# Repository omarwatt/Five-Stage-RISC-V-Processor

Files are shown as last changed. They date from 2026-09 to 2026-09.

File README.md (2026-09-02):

# Five-Stage RISC-V Processor

## Project Overview

A VHDL processor project comparing single-cycle and five-stage pipelined implementations. The design explores instruction overlap, data forwarding, hazard handling, and the FPGA resource and clock-frequency cost of pipelining.

## Main Features

- IF, ID, EX, MEM, and WB stages with interstage registers.
- Forwarding from EX/MEM and MEM/WB, prioritizing the newer result and excluding register `x0`.
- Load-use stalling and control-flow flushing.
- Branch and jump resolution in the MEM stage.
- Separate 8 KiB instruction and 8 KiB data memories.
- Stage-level instruction/PC visibility and cycle, stall, and flush counters.

## Architecture

The pipelined variant distributes the datapath across five stages. A hazard unit controls stalls, forwarding supplies recent operands, and flushing discards instructions after a control-flow redirect. Multiplication is split across EX and MEM using partial products from the lower 16 operand bits.

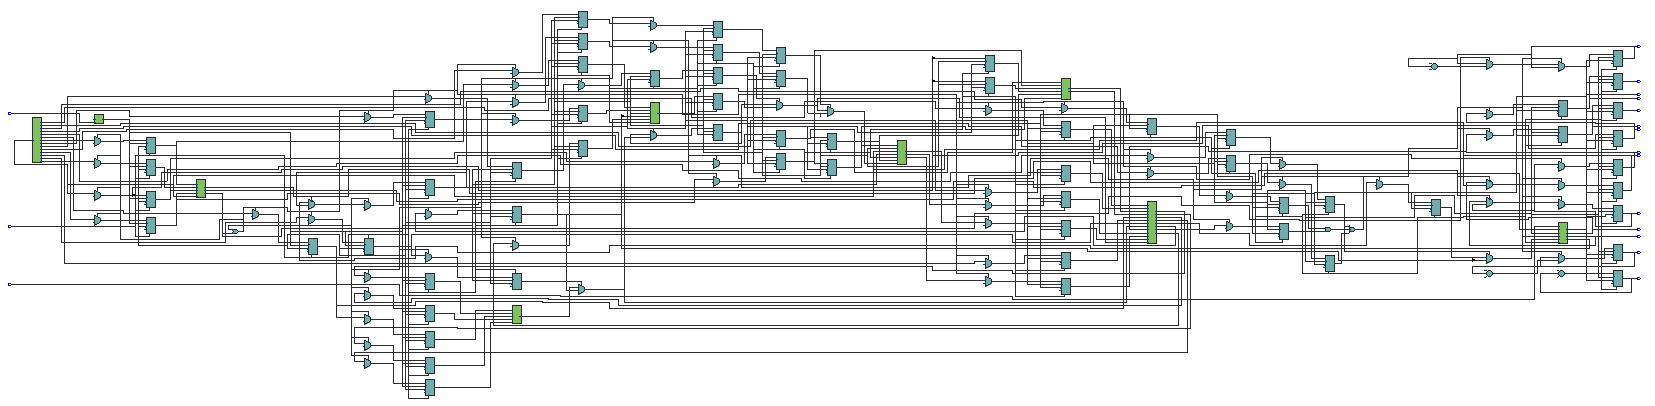
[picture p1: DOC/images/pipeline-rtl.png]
Pipelined processor RTL

*The report’s RTL view shows the processor blocks and interstage register banks.*

## Tools and Technologies

VHDL, Intel Quartus Prime 25.1, ModelSim/Questa, Intel FPGA memory primitives, and Cyclone V. The report also uses RARS as a software reference for program behavior.

## Simulation and Results

The report contains representative simulation and hardware-debug captures. The supplied testbenches provide directed stimulus rather than a complete automated ISA regression.

Archived results from `DOC/pre5.pdf`:

| Metric | Single-cycle | Pipelined |
| --- | ---: | ---: |
| Fitter ALMs | 1,448 | 1,705 |
| Fitter registers | 1,314 | 2,024 |
| MCLK Fmax | 34.99 MHz | 98.72 MHz |

The pipelined design raises reported maximum clock frequency while increasing resources. These figures do not establish application execution-time speedup.

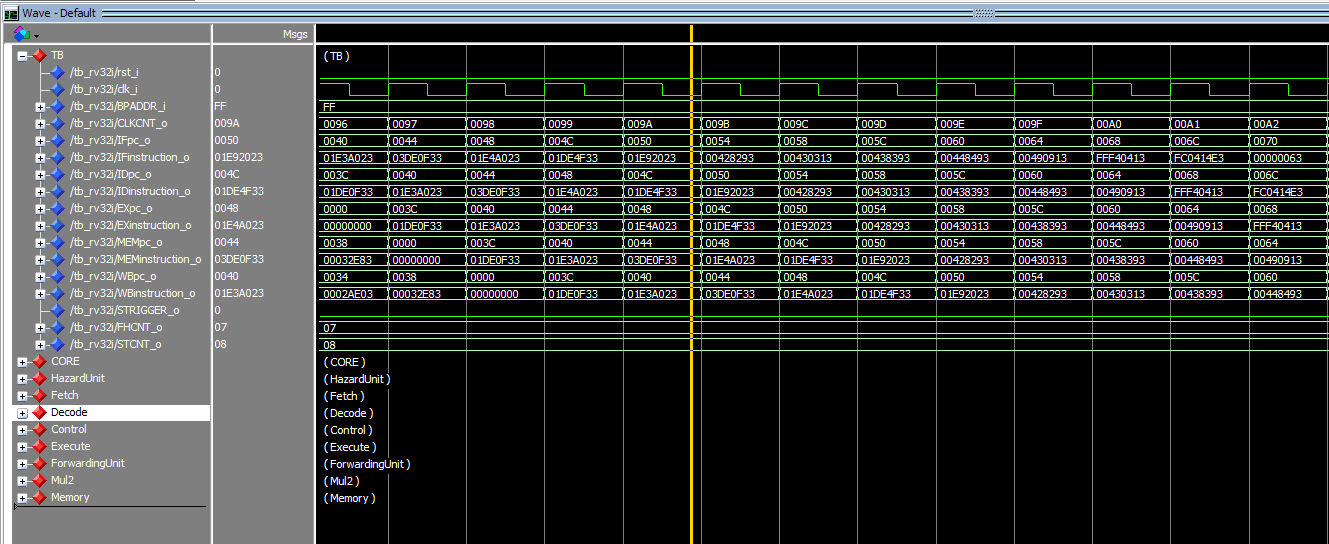
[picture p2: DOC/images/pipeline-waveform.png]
Pipeline simulation

*The IF, ID, EX, MEM, and WB program counters expose pipeline progression; STCNT and FHCNT show accumulated stalls and flushes.*

Pipeline timing result
*Quartus reports an MCLK Fmax of 98.72 MHz for the archived implementation.*

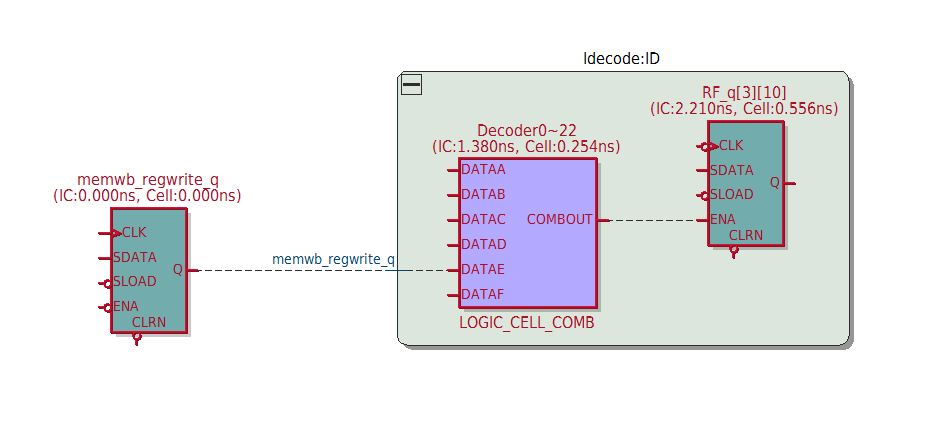
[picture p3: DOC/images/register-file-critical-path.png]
Register-file critical path

*The technology-map view traces memwb_regwrite_q through the IDECODE decoder to RF_q, locating the reported register-file write timing path.*

Pipelined data-memory readback
*The archived DTCM readback shows the benchmark’s stored result pattern. The report compares it with the single-cycle result and software reference.*

## Repository Structure

- `DUT/RV32IM_sc/`: single-cycle processor sources.
- `DUT/RV32IM_pipeline/`: pipelined processor sources.
- `TB/`: testbenches for the two variants.
- `DOC/`: project report.
- `docs/images/`: five selected design and results figures.
- `QUARTUS/`: archived implementation/debug artifacts.

## How to Run

1. Create a separate simulator project or work library for each variant: their entity and package names overlap.
2. Enable VHDL-2008 and configure Intel's `altera_mf` simulation library.
3. Set the selected variant's `G_MODELSIM` constant to `1`.
4. Supply matching instruction/data initialization images and replace the absolute paths in the memory sources.
5. Compile the selected variant's packages and DUT files in dependency order, then its testbench. Elaborate and inspect stage signals, register writes, and memory results.

## Attribution

Course project by **Omar Wattad**, based on the supplied course framework. Preserve the original source headers and course attribution.

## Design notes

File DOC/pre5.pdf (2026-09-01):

LAB5 — Single-Cycle & Pipelined RV32IM µArchitecture

Advanced CPU Architecture · Hanan Ribo · BGU Page 1 of 14

### Ben-Gurion University of the Negev

Electrical & Computer Engineering

Advanced CPU Architecture & Hardware Accelerators
Course 361-1-4693

# LAB 5 — Preparation Report

### Scalar Single-Cycle & 5-Stage Pipelined RV32IM CPU µArchitecture

Submitted by:
Omar Wattad — ID 207510819 Fidaa Abo Aissa — ID 324960996

Instructor: Hanan Ribo
June 2026

## Table of Contents

5. HDL Source File Descriptions | Error! Bookmark not defined.
7. FPGA Implementation | Error! Bookmark not defined.
8. Submission Structure | Error! Bookmark not defined.

## 1. Aim and Assignment Definition

This report documents the design, synthesis, implementation and validation of a RISC-V compatible CPU on an Intel FPGA, in two micro-architectural variants that share the same RV32IM (MULDIV-partial) instruction set:

- Part 1 — a scalar single-cycle RV32IM core, obtained by elevating the supplied single-cycle RV32I datapath with the M-extension mul instruction.
- Part 2 — a scalar 5-stage pipelined RV32IM core, obtained by slicing the single-cycle datapath into IF / ID / EX / MEM / WB stages with full data-forwarding, combinational hazard (interlock) detection, and branch/jump resolution in stage 4.
Both cores follow a Harvard organisation with separate ITCM (instruction) and DTCM (data) tightly-coupled memories of 8 kB each, a standard RISC-V register file, and a structural top level. A single PLL-derived clock (MCLK) drives the design; push-button KEY0 is the active core reset that brings the PC to the first program instruction.

### 1.1 The mul instruction and the 16-bit multiplier

From the M-extension only mul rd, rs1, rs2 is required. It multiplies the lower 16-bit half-words of rs1 and rs2 and writes the 32-bit product to rd. The 16×16 multiplication is built from the FPGA’s embedded 8-bit multipliers using four partial products:

- P0 = A_low × B_low, P1 = A_low × B_high, P2 = A_high × B_low, P3 = A_high × B_high
- M = P1 + P2, RESULT = P0 + (M << 8) + (P3 << 16)
In the single-cycle core the multiplier is purely combinational. In the pipeline it is split across two stages — the four partial products are formed in EX (Multiplier stage 1) and combined/shifted in MEM (Multiplier stage
2) — which keeps the multiplier off the critical path.

### 1.2 Signal-Tap instrumentation (IPC & breakpoint debug)

To support on-board IPC measurement and breakpoint debugging the top entity exposes the following registers, all cleared on reset:

- STCNT_o — 8-bit stall counter, increments on every clock in which a stall occurs.
- FHCNT_o — 8-bit flush counter, increments on every clock in which a flush occurs.
- BPADDR_i — 8-bit breakpoint address fed by SW7–SW0; the Signal-Tap trigger fires when IF_PC == BPADDR_i, letting us capture core signals from any PC until the buffer is full.
The instructions-per-cycle figure is verified against the relation

IPC = ( CLKCNT_o − (STCNT_o + 4 + depth · FHCNT_o) ) / CLKCNT_o = InstructionCounter / CLKCNT_o , IPC = 1/CPI

## 2. Top-Level Block Review

Both cores are structural top entities. The single-cycle top entity exposes the architectural state and datapath observation ports together with a free-running MCLK cycle counter; the pipelined top entity additionally exposes per-stage PC/instruction taps plus the stall, flush and trigger registers required for IPC and breakpoint debugging. Their I/O is summarised below.

Port | Single-cycle RV32IM_CORE | Pipelined RV32IM_CORE
Clock / reset | clk_i (50 MHz → PLL), rst_i (KEY0) | clk_i (50 MHz → PLL), rst_i (KEY0)
Debug input | — | BPADDR_i (SW7–SW0)
PC / instruction | pc_o, instruction_o | IF/ID/EX/MEM/WB pc_o & instruction_o
Control taps | RegWrite_ctrl_o, MemWrite_ctrl_o, Branch_ctrl_o, brTaken_o | (per-stage, internal)
Datapath taps | read_data1_o, read_data2_o,
write_data_o, alu_res_o | (per-stage, internal)
Memory taps | dtcm_addr_o, dtcm_data_wr_o, dtcm_data_rd_o | (internal)
Counters | mclk_cnt_o | CLKCNT_o, STCNT_o, FHCNT_o, STRIGGER_o

Table 1: Top-level port map of the single-cycle and pipelined RV32IM cores.

Each core instantiates five datapath sub-blocks — IFETCH, IDECODE, CONTROL, EXECUTE and DMEMORY — plus an altpll PLL that generates MCLK and an MCLK counter. The pipelined core adds four pipeline-register banks (IF/ID, ID/EX, EX/MEM, MEM/WB), a combinational Stall-Condition (hazard) unit and a Forwarding unit. The structural decomposition is visible in the RTL Viewer output of Section 3.

## 3. RTL Viewer Results

The Quartus RTL Viewer confirms the structural hierarchy of each core. In the single-cycle netlist the five submodules (control:CTL, Ifetch:IFE, Idecode:ID, Execute:EXE, dmemory:MEM), the PLL\G0:MCLK and the mclk_cnt register are clearly separated, with the combinational datapath flowing left-to-right in a single clock. The pipelined netlist shows the same datapath sliced by the four register banks, producing the characteristic columns of edge-triggered registers between stages.

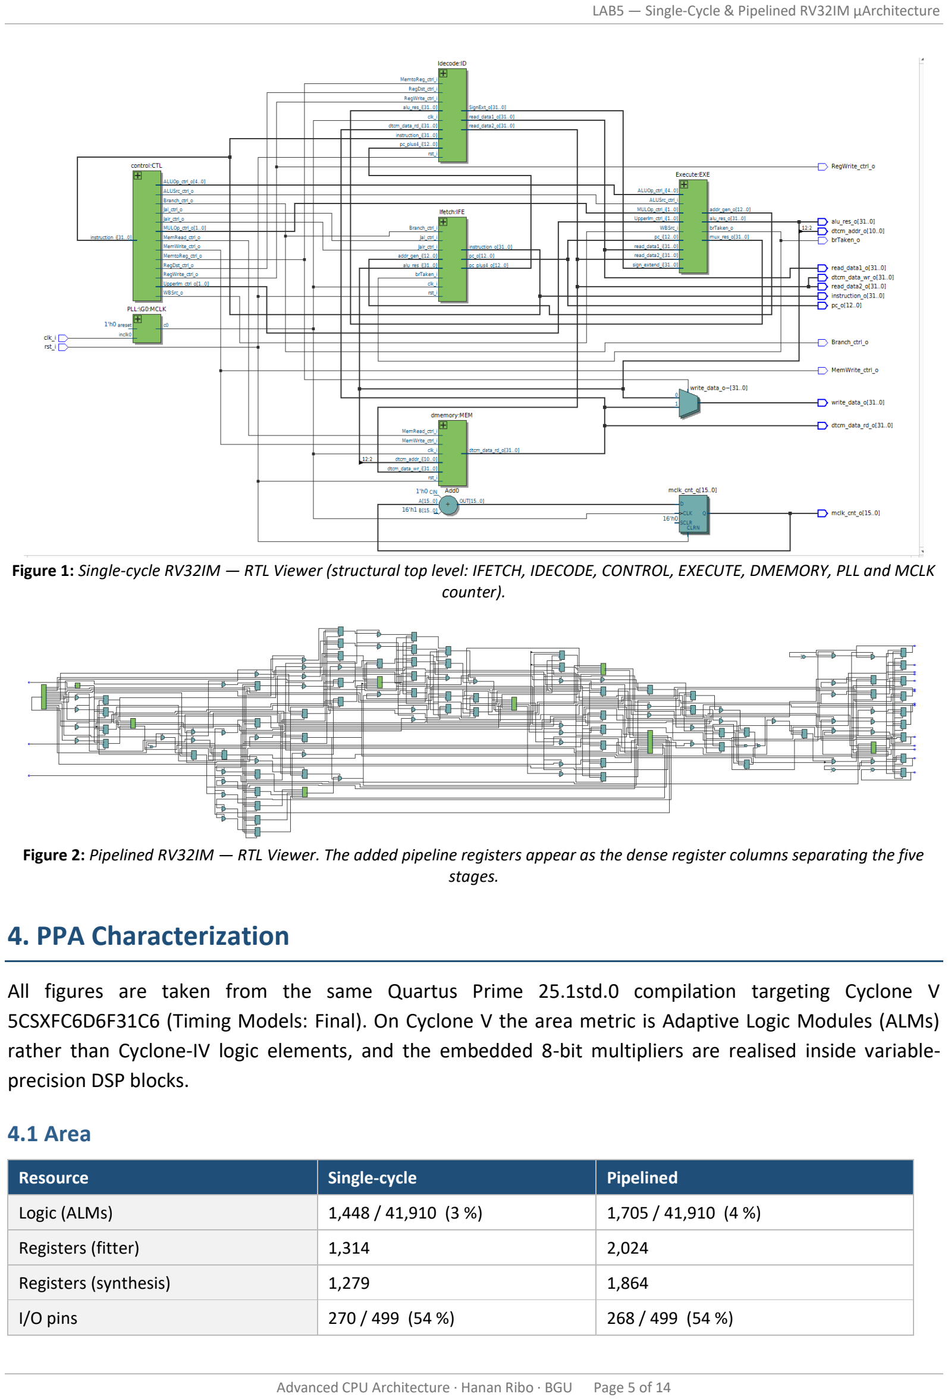
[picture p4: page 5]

Figure 1: Single-cycle RV32IM — RTL Viewer (structural top level: IFETCH, IDECODE, CONTROL, EXECUTE, DMEMORY, PLL and MCLK counter).

Figure 2: Pipelined RV32IM — RTL Viewer. The added pipeline registers appear as the dense register columns separating the five stages.

## 4. PPA Characterization

All figures are taken from the same Quartus Prime 25.1std.0 compilation targeting Cyclone V 5CSXFC6D6F31C6 (Timing Models: Final). On Cyclone V the area metric is Adaptive Logic Modules (ALMs) rather than Cyclone-IV logic elements, and the embedded 8-bit multipliers are realised inside variableprecision DSP blocks.

### 4.1 Area

Resource | Single-cycle | Pipelined
Logic (ALMs) | 1,448 / 41,910 (3 %) | 1,705 / 41,910 (4 %)
Registers (fitter) | 1,314 | 2,024
Registers (synthesis) | 1,279 | 1,864
I/O pins | 270 / 499 (54 %) | 268 / 499 (54 %)

Resource | Single-cycle | Pipelined
Block memory bits | 131,072 (2 %) | 131,072 (2 %)
RAM blocks | 14 / 553 (3 %) | 14 / 553 (3 %)
DSP blocks (4×8-bit mul) | 4 / 112 (4 %) | 4 / 112 (4 %)
PLLs | 1 / 15 (7 %) | 1 / 15 (7 %)

Table 2: Area characterization (Quartus Fitter). The pipeline costs +18 % ALMs and +54 % registers, driven by the four pipeline-register banks plus the hazard and forwarding logic; memory and DSP usage are unchanged because the ISA and the 16-bit multiplier are identical.

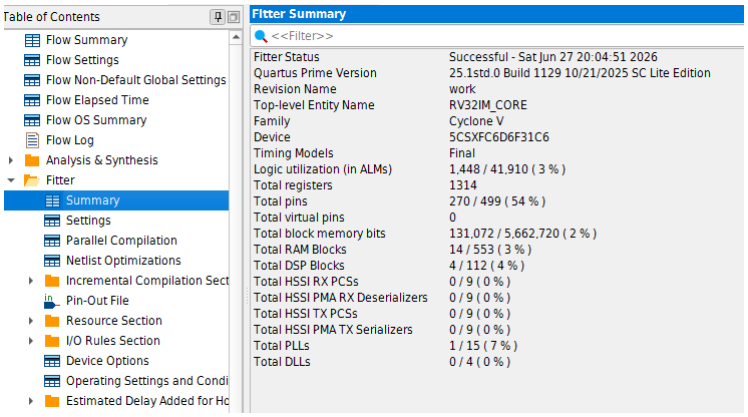
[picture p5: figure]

Figure 3: Single-cycle — Fitter resource summary (1,448 ALMs, 1,314 registers, 4 DSP, 1 PLL).

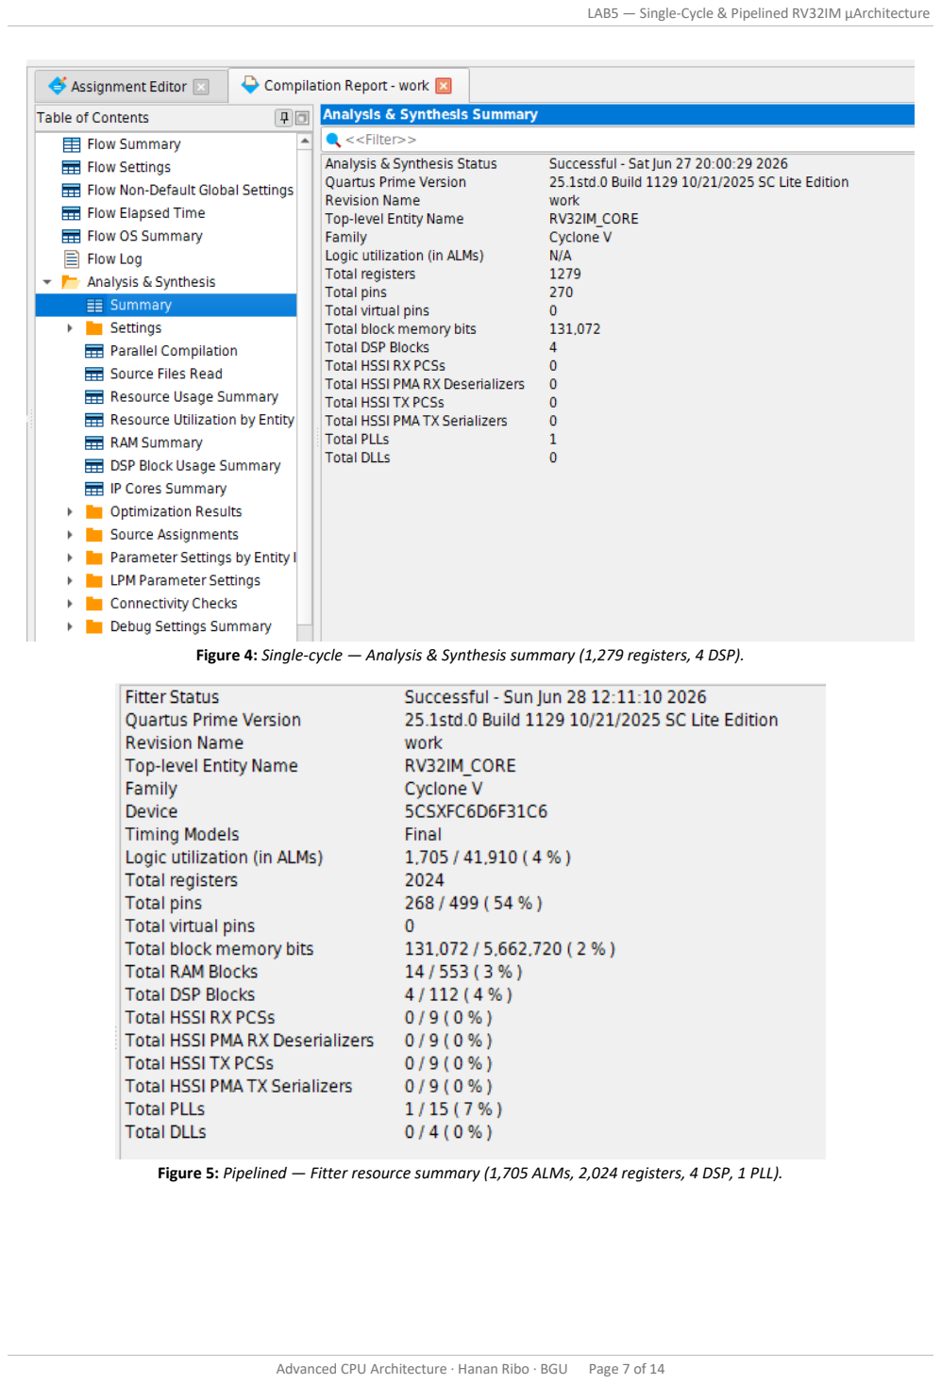
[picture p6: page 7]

Figure 4: Single-cycle — Analysis & Synthesis summary (1,279 registers, 4 DSP).

Figure 5: Pipelined — Fitter resource summary (1,705 ALMs, 2,024 registers, 4 DSP, 1 PLL).

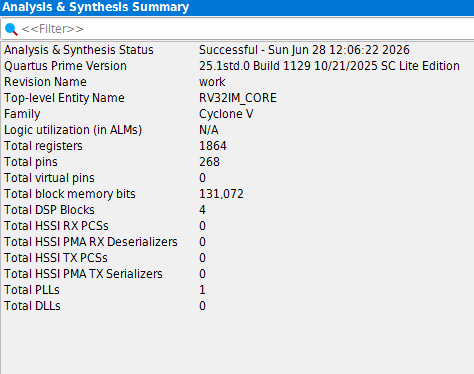
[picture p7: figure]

Figure 6: Pipelined — Analysis & Synthesis summary (1,864 registers, 4 DSP).

### 4.2 Performance

Metric | Single-cycle | Pipelined
Fmax (MCLK) | 34.99 MHz | 98.72 MHz (Slow 1100 mV 85 °C)
F_MCLK = F_sysclk | ≤ 34.99 MHz (PLL output) | ≤ 98.72 MHz (PLL output)

Critical path

Full single-cycle datapath: ITCM → decode/RF read → ALU + result mux chain → DTCM → write-back mux. Slowest sub-module: EXECUTE result-mux chain together with the DTCM RAM access.

ID register-file write/decode path: MEM/WB write-back → RF decoder (Decoder0~22) → RF_q. Slowest sub-module: IDECODE register-file write path.

Table 3: Performance characterization.

Pipelining raises Fmax from 34.99 MHz to 98.72 MHz — a 2.82× clock improvement. The theoretical ceiling for an ideally balanced 5-stage pipeline is Fmax_pipe = 5 × Fmax_single = 174.95 MHz; the achieved 98.72 MHz is ≈ 56 % of that ideal. The gap is expected: the stages are not perfectly balanced (the register-file write/decode path and the multiplier stage dominate), and the extra pipeline-register, hazard and forwarding logic adds delay that does not exist in the single-cycle datapath.

Figure 7: Single-cycle — Fmax: 34.99 MHz on the MCLK (PLL divclk).

Figure 8: Pipelined — Fmax: 98.72 MHz on the MCLK.

Figure 9: Pipelined — Fmax at the second slow corner (98.89 MHz on MCLK); 98.72 MHz is taken as the worst case.

The critical-path technology-map views below locate the slowest cells. For the single-cycle core they sit in the EXECUTE result-mux chain and the data-memory RAM block (interconnect delays ≈ 1.0–1.45 ns per hop). For the pipeline they move into the IDECODE register-file write path (Decoder0~22: IC 1.380 ns; RF_q: IC 2.210 ns).

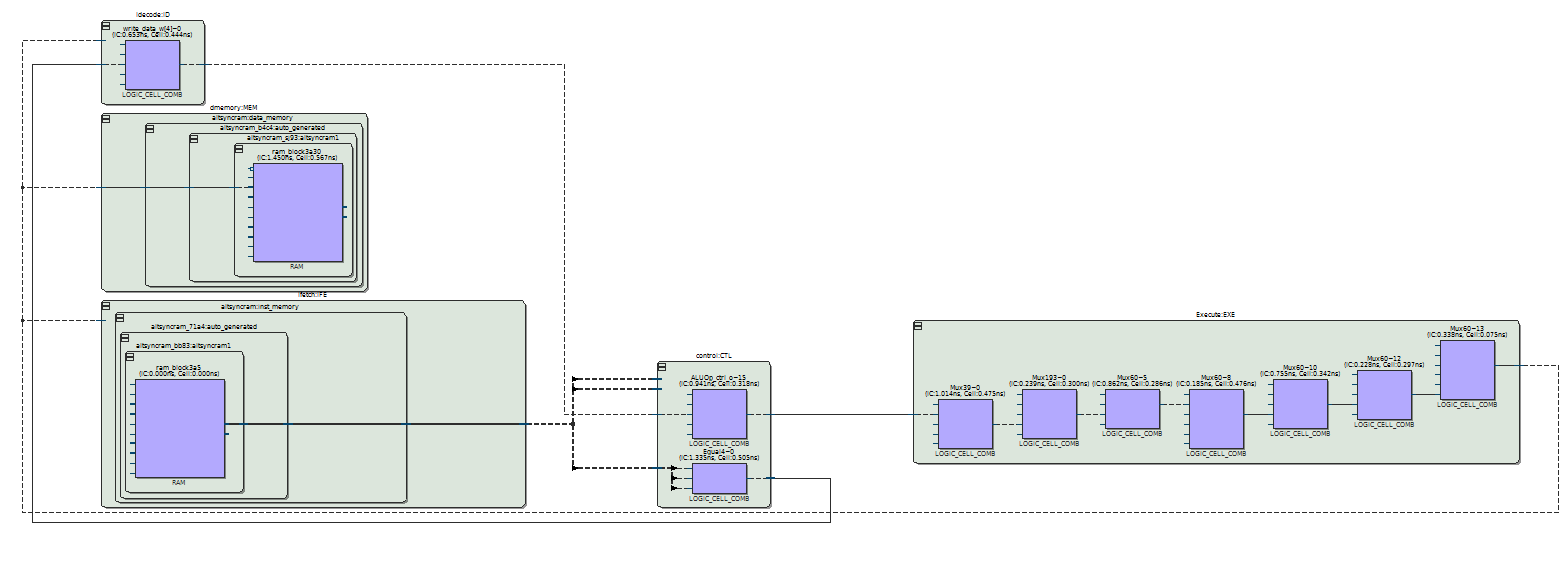
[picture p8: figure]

Figure 10: Single-cycle — critical-path technology map: EXECUTE mux chain + data-memory RAM dominate the single-cycle delay.


Figure 11: Pipelined — critical-path technology map: the dominant path is the register-file write in IDECODE.

### 4.3 Power

Power component | Single-cycle | Pipelined
Total thermal power | 472.30 mW | 595.04 mW
Core static | 415.45 mW | 417.50 mW
Core dynamic | 21.09 mW | 88.79 mW
I/O thermal | 35.76 mW | 88.76 mW

Table 4: Power characterization (PowerPlay, Final timing models). Estimation confidence is reported as Low because the .vcd toggle data is partial — the absolute numbers are indicative.

Static power is essentially identical (same device, same process) at ≈ 416 mW. Dynamic power, however, rises from 21 mW to 89 mW: the pipeline holds far more registers (2,024 vs 1,314) and clocks them ≈ 2.8× faster, so switching activity grows accordingly. I/O power also rises (35.8 → 88.8 mW) because the pipeline top entity drives many more toggling observation ports (five per-stage PC and instruction buses plus the counters) for Signal-Tap.

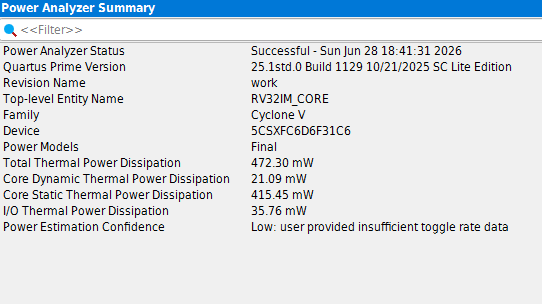
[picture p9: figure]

Figure 12: Single-cycle — PowerPlay summary: 472.30 mW total (415.45 static / 21.09 dynamic / 35.76 I/O).

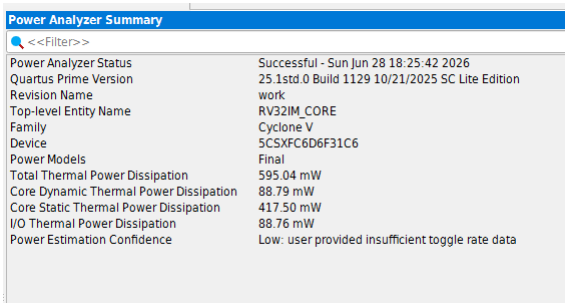
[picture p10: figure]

Figure 13: Pipelined — PowerPlay summary: 595.04 mW total (417.50 static / 88.79 dynamic / 88.76 I/O).

## 5. Functional Verification and Waveform Analysis

Verification follows the golden-model flow of the assignment: the benchmark application is run in RARS (golden), in ModelSim (RTL simulation) and on the board through Signal-Tap / ISMCE, and the resulting DTCM contents are compared. The benchmark used here writes an incrementing data pattern (1, 2, 3, …) into successive DTCM words, which makes both the data values and the instruction/PC stream easy to follow on the waveforms.

### 5.1 ModelSim RTL simulation

Single-cycle: every instruction completes in one MCLK period, so pc_o advances by 4 each cycle and mclk_cnt_o increments monotonically; alu_res_o and write_data_o produce the stored value in the same cycle the address dtcm_addr_o is presented. Pipelined: the same program is now distributed across the five stages — the per-stage taps (IF/ID/EX/MEM/WB pc & instruction) show one instruction marching down the pipeline each cycle, and STCNT_o / FHCNT_o accumulate the stalls and flushes (here STCNT_o = 08h, FHCNT_o = 07h).

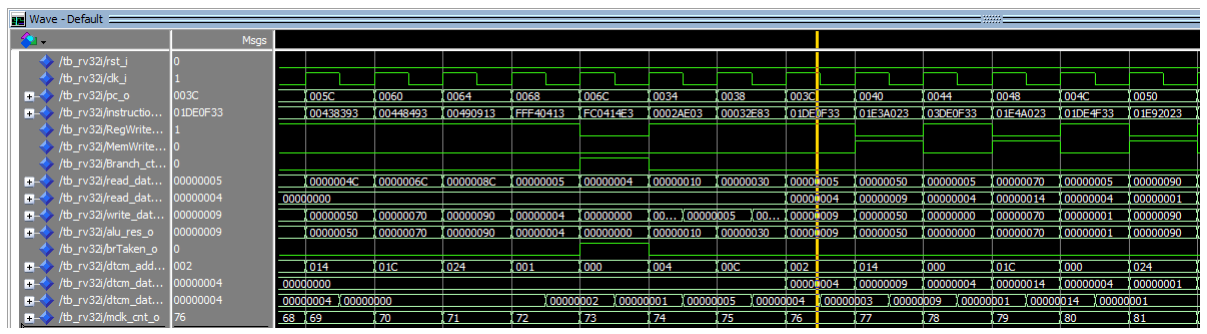
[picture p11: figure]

Figure 14: Single-cycle — ModelSim waveform of the benchmark (one instruction per MCLK; PC +4 each cycle).


Figure 15: Pipelined — ModelSim waveform of the benchmark, showing the per-stage PC/instruction taps and the STCNT/FHCNT counters.

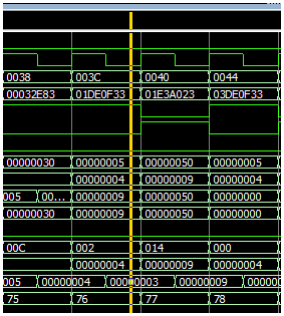
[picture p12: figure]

Figure 16: Single-cycle — add instruction.

### 5.2 On-board Signal-Tap validation

On the DE-SoC board the Signal-Tap trigger is armed at IF_PC == BPADDR_i and the core is single-stepped with Auto-run. The single-cycle captures below show the start of the program (PC sweeping 0x00→) and the closing loop branch, where Branch_ctrl_o and brTaken_o assert. The pipelined capture shows all per-stage PC/instruction taps advancing together with CLKCNT_o, STCNT_o = 08h and FHCNT_o = 07h, exactly matching the ModelSim run.

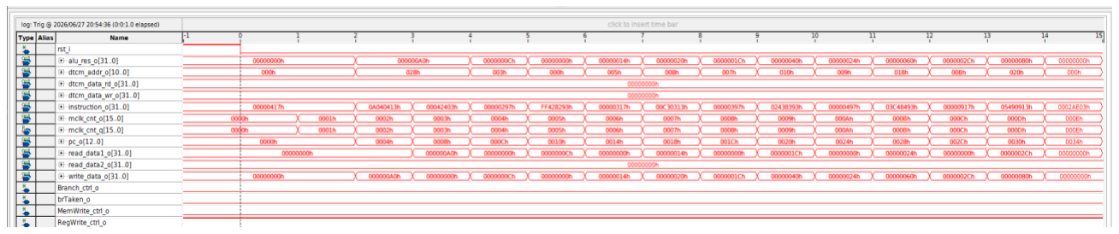
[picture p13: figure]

Figure 17: Single-cycle — Signal-Tap capture at program start (PC sweep, one instruction per cycle).

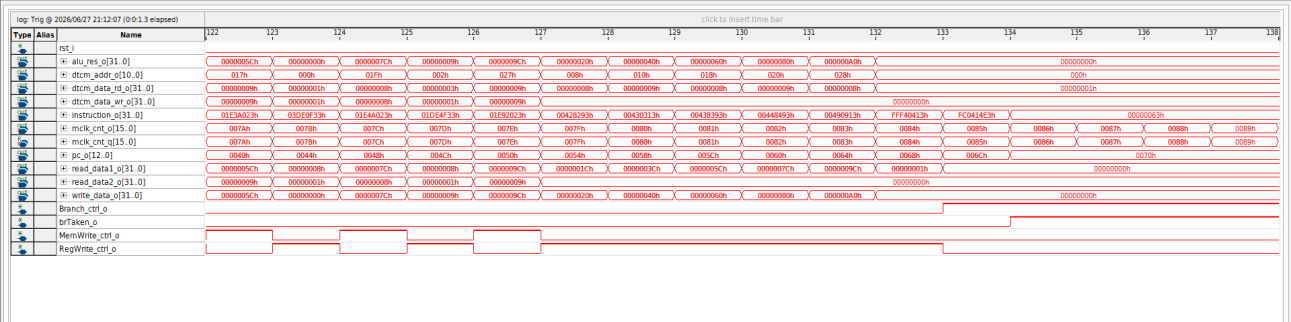
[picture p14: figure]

Figure 18: Single-cycle — Signal-Tap capture near program end: Branch_ctrl_o / brTaken_o assert on the loop branch.

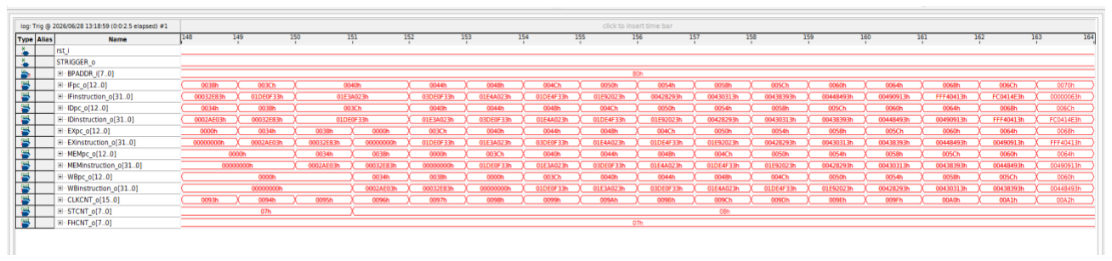
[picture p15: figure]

Figure 19: Pipelined — Signal-Tap capture: per-stage PC/instruction taps, CLKCNT_o, STCNT_o = 08h, FHCNT_o = 07h, BPADDR_i = 80h.

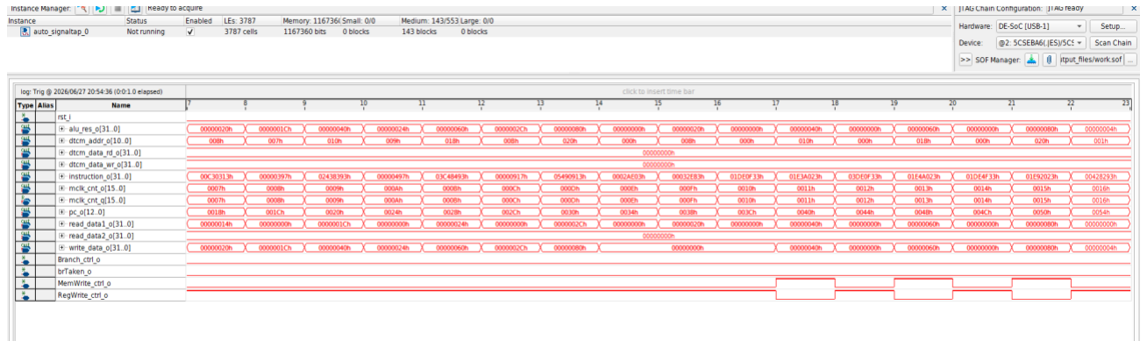
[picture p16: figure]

Figure 20: Single-cycle — Signal-Tap instance manager (auto_signaltap_0 on DE-SoC, capturing the core observation ports).

### 6.3 Golden-model memory comparison (ISMCE)

After the run the ITCM and DTCM contents are read back with the In-System Memory Content Editor and compared against the RARS DTCM.hex / DTCM.mem golden files. The ITCM holds the assembled program image; the DTCM holds the incrementing result pattern. Both cores produce byte-identical DTCM contents, which closes the golden-model check.

Figure 21: Single-cycle — ITCM contents read back via ISMCE (assembled program image).

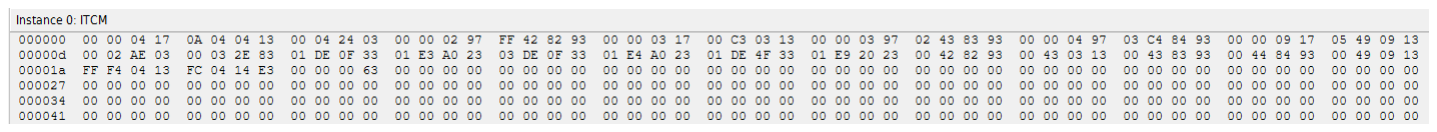
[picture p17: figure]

Figure 22: Pipelined — ITCM contents (identical program image).

Figure 23: Single-cycle — DTCM contents: the incrementing result pattern written by the benchmark.

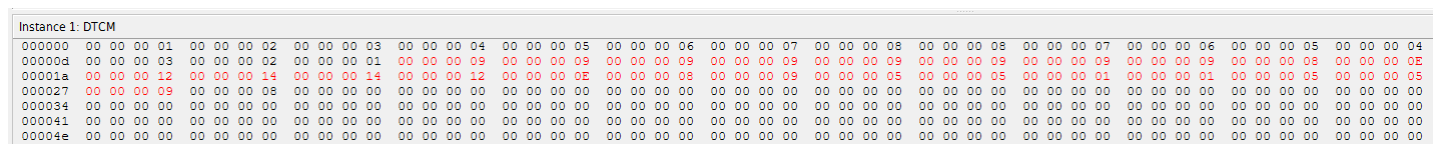
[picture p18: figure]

Figure 24: Pipelined — DTCM contents: byte-identical to the single-cycle and to the RARS golden model.

Figure 25: Pipelined — DTCM.mem golden dump (ModelSim) used as the reference for the comparison.

Per the assignment, basic waveforms for benchmark applications test1–test4 are required. The captures above correspond to the representative benchmark; the remaining test1–test4 waveforms should be inserted here in the same SC-over-pipeline format once captured.

### 5.4 IPC analysis

For the single-cycle core there are no stalls or flushes (STCNT = FHCNT = 0), so CPI = 1 and IPC = 1 by construction. For the pipeline, IPC is recovered from the on-chip counters using the relation of Section 1.2. With the captured values (STCNT_o = 8, FHCNT_o = 7, flush depth = 3) the executed-instruction count is CLKCNT_o − (8 + 4 + 3·7) = CLKCNT_o − 33; at the capture point CLKCNT_o ≈ 162 this gives ≈ 129 instructions and IPC ≈ 0.80 (CPI ≈ 1.25). The two sides of the IPC equation match the ModelSim instruction count, confirming correct stall/flush accounting. The final IPC must be read from the end-of-program CLKCNT_o.

## 6. Conclusions

Both RV32IM cores were verified functionally identical (matching DTCM golden model in RARS, ModelSim and on-board ISMCE) while exhibiting the expected PPA trade-off. Pipelining raised Fmax 2.82× (34.99 → 98.72 MHz) at a cost of +18 % ALMs, +54 % registers and ~4× dynamic power, with the critical path migrating from the single-cycle EXECUTE/DTCM combinational path to the pipelined register-file write path. The achieved Fmax reaches ~56 % of the ideal 5× ceiling, limited by stage imbalance and the added hazard/forwarding/register overhead — a textbook illustration of the single-cycle versus pipelined design space.

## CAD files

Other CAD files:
QUARTUS/stp2.stp
